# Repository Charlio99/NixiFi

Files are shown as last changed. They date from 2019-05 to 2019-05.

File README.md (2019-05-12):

# NixiFi







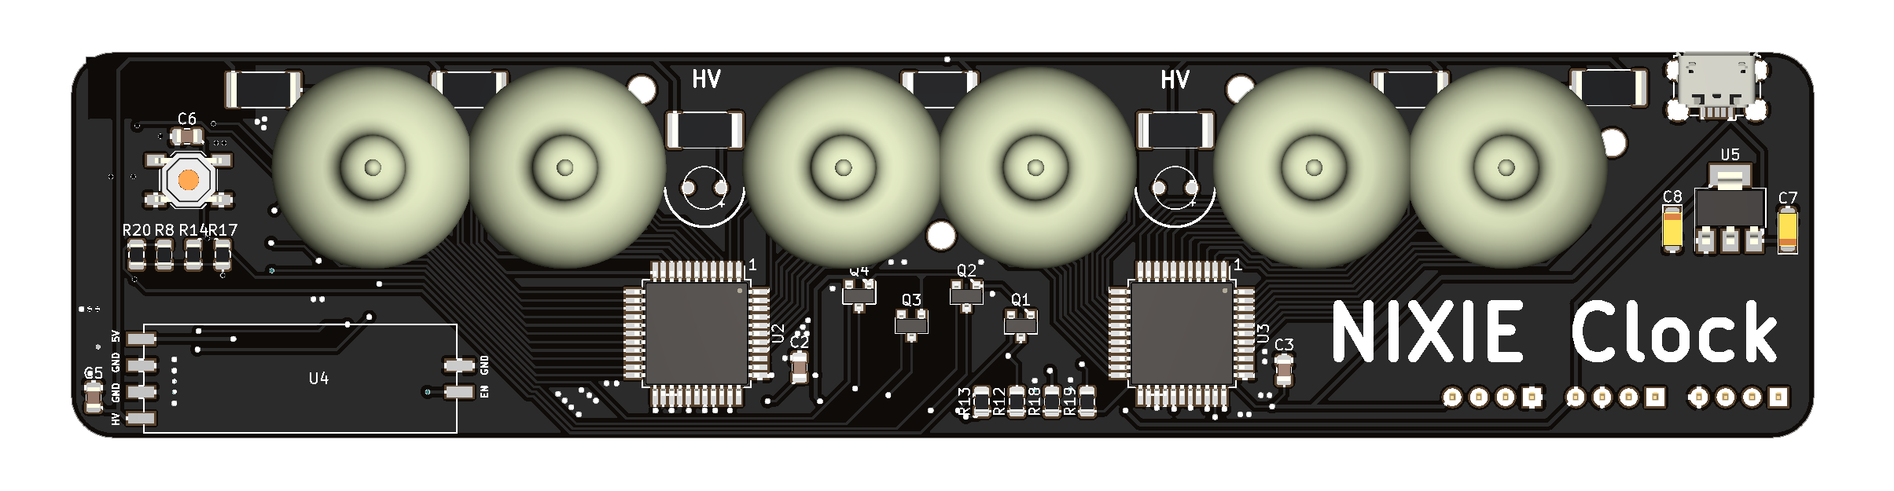
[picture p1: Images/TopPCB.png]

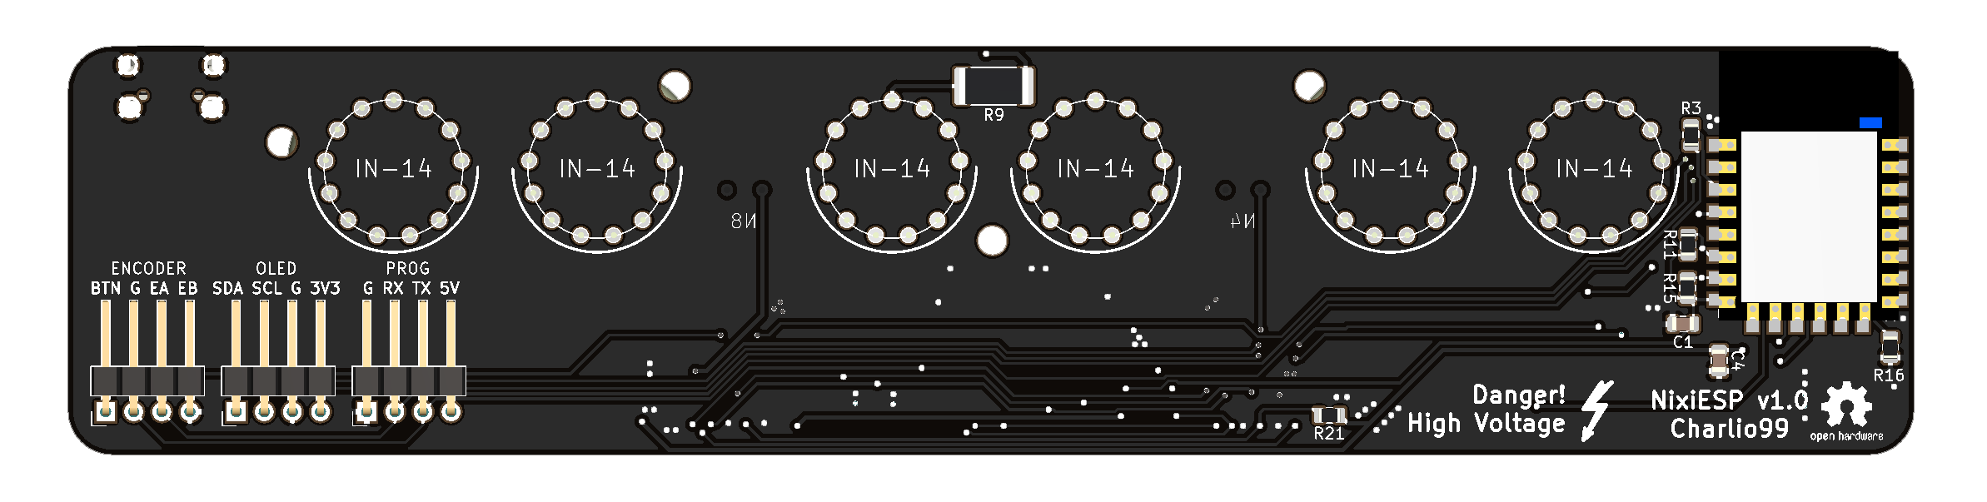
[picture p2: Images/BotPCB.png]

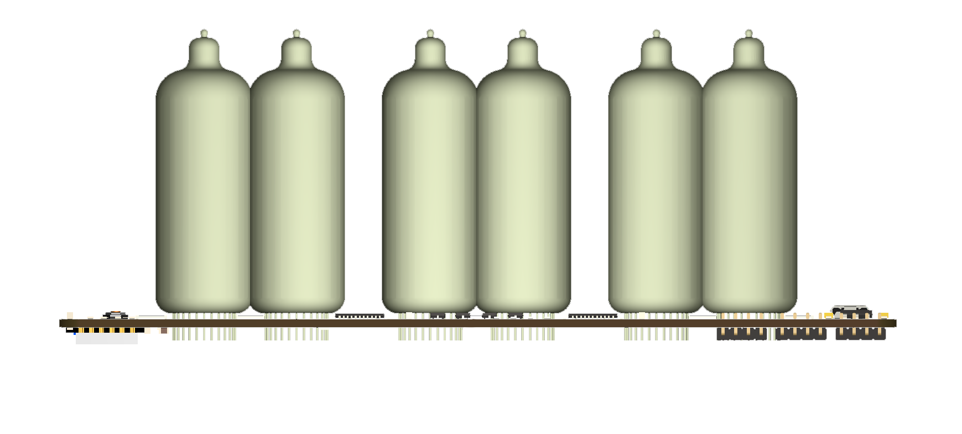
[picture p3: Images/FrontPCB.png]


NixiFi is an all in one WiFi Nixie NTP Clock board, only you have to do is to solder the components and upload the code!.

# Features

  - ESP8266 based (Arduino IDE code).
  - NTP Time.
  - No spare PSUs messing around, the 170v output is handled by a small smd PSU (link in BOM).
  - 5V Powered and it only draws 1.5-2W.
  - Oled display and encoder to configure zone, auto DST, the cathode poisoning prevention, auto shutdown between specific hours, etc.
  - Go over all numbers at specific time to avoid cathode poisoning (can be configured with the OLED display)
  - Plug and play. Once you upload the code, a WiFi network will appear, connect to it following the instructions in the OLED display.

### BOM

I mainly use JLCPCB and LCSC for PCB and components.

| Component | Quantity | Link | Price |
| --- | --- | --- | --- |
| ESP-12E | 1 | https://lcsc.com/product-detail/WIFI-Modules_ESP-12E_C89297.html | $2.2 |
| 170v PSU | 1 | https://www.ebay.es/itm/141728921034 | $9.99 |
| 100nF | 4 | https://lcsc.com/product-detail/Multilayer-Ceramic-Capacitors-MLCC-SMD-SMT_SAMSUNG_CL21B104KBCNNNC_100nF-104-10-50V_C1711.html | $0.46 |
| 1uF | 2 | https://lcsc.com/product-detail/Multilayer-Ceramic-Capacitors-MLCC-SMD-SMT_1uF-106-10-16V_C94122.html | $0.3 |
| 10uF Tantalum | 2 | https://lcsc.com/product-detail/Tantalum-Capacitors_AVX_TAJA106K010RNJ_10uF-106-10-10V_C7177.html | $0.24 |
| USB Micro B | 1 | https://lcsc.com/product-detail/Micro-USB-Connectors_Korean-Hroparts-Elec-U-F-M5DD-Y-1_C91467.html | $0.17 |
| OLED 0.96" | 1 | https://es.aliexpress.com/item/32713614136.html | $1.76 |
| Encoder | 1 | https://es.aliexpress.com/item/Rotary-Encoder-Module-Brick-Sensor-Development-for-arduino-KY-040/32462116984.html | $0.68 |
| 2N7002 | 4 | https://lcsc.com/product-detail/MOSFET_ON-Semicon_2N7002LT1G_ON-Semicon-ON-2N7002LT1G_C16338.html | $0.5 |
| 27K | 6 | https://lcsc.com/product-detail/Chip-Resistor-Surface-Mount_27KR-2702-1_C175357.html | $0.4 |
| 100K | 2 | https://lcsc.com/product-detail/Chip-Resistor-Surface-Mount_100KR-1003-1_C147046.html | $0.85 |
| 10K | 13 | https://lcsc.com/product-detail/Chip-Resistor-Surface-Mount_10KR-103-5_C100047.html | $0.14 |
| Header 4 pins | 3 | https://es.aliexpress.com/item/32847365702.html | $0.77 |
| HV5622 | 2 | https://www.arrow.com/en/products/hv5622pg-g/microchip-technology | $12.32 |
| AMS1117-3.3 | 1 | https://lcsc.com/product-detail/Low-Dropout-Regulators-LDO_AMS_AMS1117-3-3_AMS1117-3-3_C6186.html | $0.57 |
| | | **TOTAL** | **$31.35**|

Take in account that some components must be ordered in larger batches that the quantity needed and shipping costs are not included in the BOM.

### Todos

 - Adapt PCB for making it compatible with IN-8-2 without the need of modifying the IN-8-2. (At the moment it can be done cutting the dot pin and bending pin 1 to be in place of the dot.)
 - Improve README
 
### License

GNU Public License 3.0
Please, if you pretend to use it for comercial uses, contact me before

### Photos
NixiFi rev1.0
NixiFi rev1.0
NixiFi rev1.0

**Open Source FTW, Hell Yeah!**

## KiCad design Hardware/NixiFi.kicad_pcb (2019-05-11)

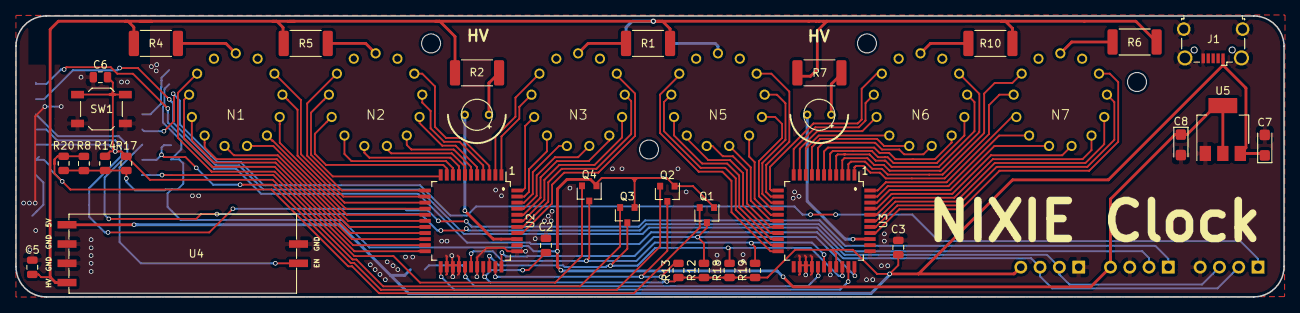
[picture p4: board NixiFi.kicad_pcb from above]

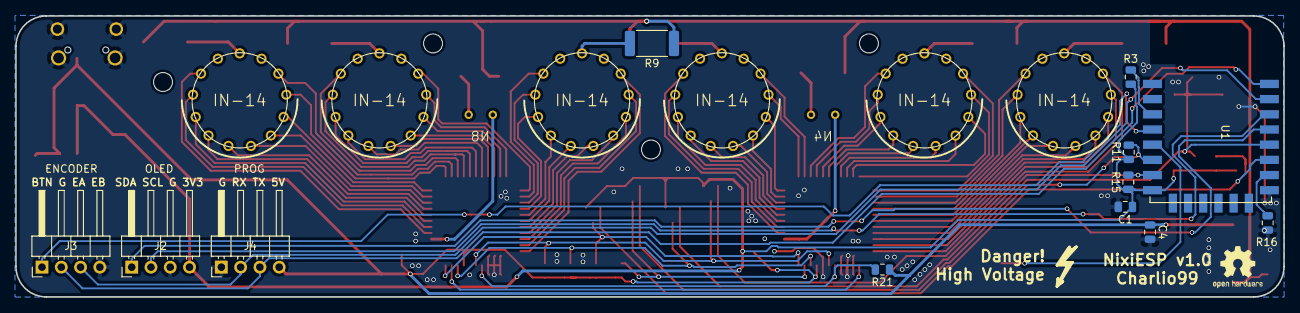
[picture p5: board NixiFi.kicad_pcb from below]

Board: 2 copper layers, 167.0 x 37.0 mm, 51 parts (18 on the bottom side), 92 nets.

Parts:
C1, C6: 100nF; C_0805_2012Metric
C2, C3: 1uF; C_0805_2012Metric
C4, C5: 0.1uF; C_0805_2012Metric
C7, C8: C; CP_EIA-3216-12_Kemet-S
J1: USB_B_Micro; USB_Micro-B_Wuerth_629105150521_CircularHoles
J2: OLED; PinHeader_1x04_P2.54mm_Horizontal
J3: ENCODER; PinHeader_1x04_P2.54mm_Horizontal
J4: PROG; PinHeader_1x04_P2.54mm_Horizontal
N1, N2, N3, N5, N6, N7: IN-14; russian-nixies-IN-14
N4, N8: IN-3; russian-nixies-IN-3
Q1, Q2, Q3, Q4: 2N7002; SOT-23
R1, R4, R5, R6, R9, R10: 27K; R_2512_6332Metric
R2, R7: 100K; R_2512_6332Metric
R3, R8, R11, R12, R13, R14, R15, R16, R17, R18, R19, R20, R21: 10K; R_0805_2012Metric
SW1: PROG_MODE; SW_SPST_TL3342
U1: ESP-12E; ESP-12E_SMD
U2, U3: HV5622; PQFP-44_10x10mm_P0.8mm
U4: PSU; TypeD-PowerSupply
U5: AMS1117-3.3; SOT-223-3_TabPin2

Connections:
+3V3: C1.1, C8.1, J2.4, Q1.1, Q2.1, Q3.1, Q4.1, R3.2, R8.1, R11.1, R14.1, R15.1, R17.1, R20.1, U1.8, U5.2
+5V: C2.1, C3.1, C4.1, C7.1, J1.1, J4.4, R12.1, R13.1, R18.1, R19.1, R21.1, U2.30, U3.30, U4.1, U5.3
/BL: Q1.3, R12.2, U2.33, U3.33
/BL_PIN: Q1.2, R8.2, R20.2, U1.11
/BTN: J3.1, U1.4
/CLK: Q4.3, R19.2, U2.28, U3.28
/CLK_PIN: Q4.2, R15.2, U1.7
/DATA_IN: Q2.3, R13.2, U2.32
/DATA_IN_PIN: Q2.2, R11.2, U1.6
/ENABLE: U1.5, U4.6
/GPIO15: R16.1, U1.10
/LE: Q3.3, R18.2, U2.31, U3.31
/LE_PIN: C6.2, Q3.2, R14.2, R17.2, SW1.1, U1.12
/RXD: J3.3, J4.2, U1.15
/SCL: J2.2, U1.14
/SDA: J2.1, U1.13
/TXD: J3.2, J4.3, U1.16
GND: C1.2, C2.2, C3.2, C4.2, C5.1, C6.1, C7.2, C8.2, J1.5, J1.6, J2.3, J3.4, J4.1, R16.2, SW1.2, U1.9, U2.24, U2.25, U2.26, U2.29, U2.34, U3.24, U3.25, U3.26, U3.29, U3.34, U4.2, U4.3, U4.5, U5.1
HT: C5.2, R1.1, R2.1, R4.1, R5.1, R6.1, R7.1, R9.1, R10.1, U4.4
unnamed: N1.0, U2.13
unnamed: N1.1, U2.22
unnamed: N1.2, U2.21
unnamed: N1.3, U2.20
unnamed: N1.4, U2.19
unnamed: N1.5, U2.18
unnamed: N1.6, U2.17
unnamed: N1.7, U2.16
unnamed: N1.8, U2.15
unnamed: N1.9, U2.14
unnamed: N1.A, R4.2
unnamed: N2.0, U2.3
unnamed: N2.1, U2.12
unnamed: N2.2, U2.11
unnamed: N2.3, U2.10
unnamed: N2.4, U2.9
unnamed: N2.5, U2.8
unnamed: N2.6, U2.7
unnamed: N2.7, U2.6
unnamed: N2.8, U2.5
unnamed: N2.9, U2.4
unnamed: N2.A, R5.2
unnamed: N3.0, U2.37
unnamed: N3.1, U2.2
unnamed: N3.2, U2.1
unnamed: N3.3, U2.44
unnamed: N3.4, U2.43
unnamed: N3.5, U2.42
unnamed: N3.6, U2.41
unnamed: N3.7, U2.40
unnamed: N3.8, U2.39
unnamed: N3.9, U2.38
unnamed: N3.A, R1.2
unnamed: N4.A, R2.2
unnamed: N4.K, U2.36
unnamed: N5.0, U3.13
unnamed: N5.1, U3.22
unnamed: N5.2, U3.21
unnamed: N5.3, U3.20
unnamed: N5.4, U3.19
unnamed: N5.5, U3.18
unnamed: N5.6, U3.17
unnamed: N5.7, U3.16
unnamed: N5.8, U3.15
unnamed: N5.9, U3.14
unnamed: N5.A, R9.2
unnamed: N6.0, U3.3
unnamed: N6.1, U3.12
unnamed: N6.2, U3.11
unnamed: N6.3, U3.10
unnamed: N6.4, U3.9
unnamed: N6.5, U3.8
unnamed: N6.6, U3.7
unnamed: N6.7, U3.6
unnamed: N6.8, U3.5
unnamed: N6.9, U3.4
unnamed: N6.A, R10.2
unnamed: N7.0, U3.37
unnamed: N7.1, U3.2
unnamed: N7.2, U3.1
unnamed: N7.3, U3.44
unnamed: N7.4, U3.43
unnamed: N7.5, U3.42
unnamed: N7.6, U3.41
unnamed: N7.7, U3.40
unnamed: N7.8, U3.39
unnamed: N7.9, U3.38
unnamed: N7.A, R6.2
unnamed: N8.A, R7.2
unnamed: N8.K, U3.36
unnamed: R3.1, U1.3
unnamed: R21.2, U2.27, U3.27
unnamed: U2.23, U3.32

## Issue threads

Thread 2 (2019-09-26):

kicad libraries

alexiumihai1, 2019-09-26:
Hello,
Interesting project.
Can you put the libraries for pcb and schematics please.

Thank you.

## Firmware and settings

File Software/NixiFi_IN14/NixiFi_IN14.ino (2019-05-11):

/* 
 *    ESP Nixie Clock 
 *	  Copyright (C) 2019  Larry McGovern
 *	
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
 *    This program is distributed in the hope that it will be useful,
 *    but WITHOUT ANY WARRANTY; without even the implied warranty of
 *    MERCHANTABILITY or FITNESS FOR A PARTICULAR PURPOSE.  See the
 *    GNU General Public License <http://www.gnu.org/licenses/> for more details.
 */
	
#include <ESP8266WiFi.h>
#include <NTPClient.h>
#include <WiFiUdp.h>
#include <TimeLib.h>
#include <Timezone.h>
#include <Wire.h>
#include <WiFiManager.h>
#include <EEPROM.h>
#include <Adafruit_GFX.h>
#include <Adafruit_SSD1306.h>
#include <avdweb_Switch.h>

#include "NixieDisplay.h"
#include "HvSupply.h"
#include "Globals.h"

#define AP_NAME "NixiFi"
#define AP_PASSWORD "DopeClock"

#define CLOCK_COLON //  Comment out if not using colon separator PCB

const int encoderPinA = 3;
const int encoderPinB = 1;
const int encoderButtonPin = 16;

NixieDisplay nixie;
HvSupply hv_supply;

WiFiUDP ntpUDP;
NTPClient timeClient(ntpUDP, "time.nist.gov", 0, 7200000); // Update time every two hours

// Set timezone rules.  Offsets set to zero, since they will be loaded from EEPROM
TimeChangeRule myDST = {"DST", Second, Sun, Mar, 2, 0};    
TimeChangeRule mySTD = {"STD", First, Sun, Nov, 2, 0};     
Timezone myTZ(myDST, mySTD);

#define OLED_RESET  LED_BUILTIN
#define SCREEN_WIDTH 128 // OLED display width, in pixels
#define SCREEN_HEIGHT 64 // OLED display height, in pixels
Adafruit_SSD1306 display(SCREEN_WIDTH, SCREEN_HEIGHT, &Wire, OLED_RESET);

const int debouncePeriod = 50;
const int longPressPeriod = 3000;  // Set longPressPeriod to 3 seconds.  Will manually turn on/off Nixies if button held for longer than 3 sec.
Switch encoderButton = Switch(encoderButtonPin, INPUT_PULLUP, LOW, debouncePeriod, longPressPeriod);

 
int encoderPos, encoderPosPrev;

enum Menu {
  TOP,
  SETTINGS1,
  SETTINGS2,
  SET_UTC_OFFSET,
  ENABLE_DST,
  SET_12_24,
  BLINK_COLON,
  CATHODE_PROTECT,
  AUTO_SHUTOFF,
  AUTO_SHUTOFF_ENABLE,
  AUTO_SHUTOFF_OFFTIME,
  AUTO_SHUTOFF_ONTIME,
  SHOW_ZERO,
  RESET_WIFI,
  SCREENSAVER_MENU,
  SCREENSAVER
} menu;

// EEPROM addresses
const int EEPROM_addr_UTC_offset  = 0; 
const int EEPROM_addr_DST         = 1;  
const int EEPROM_addr_12_24       = 2; 
const int EEPROM_addr_protect     = 3; 
const int EEPROM_addr_shutoff_en  = 4;
const int EEPROM_addr_shutoff_off = 5;
const int EEPROM_addr_shutoff_on  = 6;
const int EEPROM_addr_showzero    = 7;
const int EEPROM_addr_blink_colon = 8;
const int EEPROM_addr_screensaver = 9;

bool enableDST;         // Flag to enable DST
bool set12_24;          // Flag indicating 12 vs 24 hour time (0 = 12, 1 = 24);
bool showZero;          // Flag to indicate whether to show zero in the hour ten's place
bool enableBlink;       // Flag to indicate whether center colon should blink

uint8_t ssOption;       // Screen saver option (0=disabled, 1=scrolling image, 2=turn off OLED)

uint8_t interval_indx; // Cathode protection interval index
const int num_intervals = 8;
const int intervals[num_intervals] = {0, 1, 5, 10, 15, 20, 30, 60};  // Intervals in minutes, with 0 = off

bool enableAutoShutoff; // Flag to enable/disable nighttime shut off
int autoShutoffOfftime, autoShutoffOntime;  // On and off times from 0 to 95 in 15 minute intervals

time_t protectTimer = 0, menuTimer = 0;
bool nixieOn = true, manualOverride = false;
bool initProtectionTimer = false;  // Set true at the top of the hour to synchronize protection timer with clock

// Screensaver Bitmaps
#define INVADER_HEIGHT   16
#define INVADER_WIDTH    24
static const unsigned char PROGMEM invader1_bmp[] =
{ B00000110, B00000000, B01100000,
  B00000110, B00000000, B01100000,
  B01100001, B10000001, B10000110,
  B01100001, B10000001, B10000110,
  B01100111, B11111111, B11100110,
  B01100111, B11111111, B11100110,
  B01111110, B01111110, B01111110,
  B01111110, B01111110, B01111110,
  B01111111, B11111111, B11111110,
  B01111111, B11111111, B11111110,
  B00011111, B11111111, B11111000,
  B00011111, B11111111, B11111000,
  B00000110, B00000000, B01100000,
  B00000110, B00000000, B01100000,
  B00011000, B00000000, B00011000,
  B00011000, B00000000, B00011000};
        
static const unsigned char PROGMEM invader2_bmp[] =
{ B00000110, B00000000, B01100000,
  B00000110, B00000000, B01100000,
  B00000001, B10000001, B10000000,
  B00000001, B10000001, B10000000,
  B00000111, B11111111, B11100000,
  B00000111, B11111111, B11100000,
  B00011110, B01111110, B01111000,
  B00011110, B01111110, B01111000,
  B01111111, B11111111, B11111110,
  B01111111, B11111111, B11111110,
  B01100111, B11111111, B11100110,
  B01100111, B11111111, B11100110,
  B01100110, B00000000, B01100110,
  B01100110, B00000000, B01100110,
  B00000001, B11100111, B10000000,
  B00000001, B11100111, B10000000};
   
void setup() {
  Serial.begin(115200);
  pinMode(encoderPinA, INPUT_PULLUP);
  pinMode(encoderPinB, INPUT_PULLUP);

  display.begin(SSD1306_SWITCHCAPVCC, 0x3C);  // OLED I2C Address, may need to change for different device,
                                              // Check with I2C_Scanner
  display.setTextSize(1);
  display.setTextColor(WHITE);
  display.clearDisplay();
  
  display.setCursor(0,0);
  display.println("Connecting...");
  display.println();
  display.println("Cycle Power after a");
  display.println("few minutes if no");
  display.print("connection.");
  display.display();

    // Setup WiFiManager
  WiFiManager MyWifiManager;
  MyWifiManager.setAPCallback(configModeCallback);
  MyWifiManager.autoConnect(AP_NAME,AP_PASSWORD); // Default password is PASSWORD, change as needed
  
  display.clearDisplay();
  display.setCursor(0,0);
  display.print("Wifi Connected");
  display.display();

  timeClient.begin();

  display.setCursor(0,28);
  display.println("Updating local time");
  display.display();
  while (!timeClient.update()) {
    delay(500);
    display.print(".");
    display.display();
  }

  EEPROM.begin(10);
  
  // Read UTC offset from EEPROM
  int utc_offset = (((int)EEPROM.read(EEPROM_addr_UTC_offset)+12) % 24) - 12;

  // Read Daylight Savings Time setting from EEPROM
  enableDST = EEPROM.read(EEPROM_addr_DST) != 0;

  mySTD.offset = utc_offset * 60;
  myDST.offset = mySTD.offset;
  if (enableDST) {
    myDST.offset += 60;
  }
  myTZ = Timezone(myDST, mySTD);

  // Read 12/24 hour setting from EEPROM
  set12_24 =  EEPROM.read(EEPROM_addr_12_24) != 0;

  // Read cathode proection interval from EEPROM
  interval_indx = EEPROM.read(EEPROM_addr_protect);
  if (interval_indx >= num_intervals) interval_indx = 0;

  // Read auto shutoff settings
  enableAutoShutoff  = EEPROM.read(EEPROM_addr_shutoff_en) != 0;
  autoShutoffOfftime = (int)EEPROM.read(EEPROM_addr_shutoff_off);
  autoShutoffOntime  = (int)EEPROM.read(EEPROM_addr_shutoff_on);
  if (autoShutoffOfftime > 95) autoShutoffOfftime = 0;  // 96 15-minute intervals in day
  if (autoShutoffOntime > 95) autoShutoffOntime = 0;

  // Read show zero setting from EEPROM
  showZero = EEPROM.read(EEPROM_addr_showzero) != 0;

  // Read colon blink setting from EEPROM
  enableBlink = EEPROM.read(EEPROM_addr_blink_colon) != 0;

  // Read screensaver setting from EEPROM
  ssOption = EEPROM.read(EEPROM_addr_screensaver);
  if (ssOption > 2) ssOption = 0;
  
  menu = TOP;
  updateSelection();

  timeClient.update();
  setTime(myTZ.toLocal(timeClient.getEpochTime()));
  hv_supply.begin();
  nixie.begin();
  displayTime();
  menuTimer = now();
}

void loop() {  
  updateEncoderPos();
  encoderButton.poll();

  // If button held for longer than 3 seconds, toggle Nixie tubes on/off
  if (encoderButton.longPress()){
    manualOverride = true;  // Overrides auto shutoff for this period
    nixieOn = !nixieOn;
    menu = TOP;
    updateSelection(); 
  }

  if (encoderButton.pushed()) {
    menuTimer = now();  
    updateMenu();
   }

  timeClient.update();
  setTime(myTZ.toLocal(timeClient.getEpochTime()));

  // Cathode protection logic
  if (interval_indx > 0) {  // Cathode protection is enabled
    if ((menu != SET_UTC_OFFSET) && (menu != ENABLE_DST)) { // Changing UTC offset or DST setting can disrupt protection timer
      // At the first top of the hour, initialize cathode protection logic timer
      if (!initProtectionTimer && (minute() == 0)) {  
        protectTimer = 0;   // Ensures protection logic will be immediately triggered                                     
        initProtectionTimer = true;
      }
      if ((now() - protectTimer) >= 60 * intervals[interval_indx]) {
        protectTimer = now();
        // The current time can drift slightly relative to the protectTimer when NIST time is updated
        // Need to make a small adjustment to the timer to ensure it is triggered at the minute change
        protectTimer -= ((second()+30)%60 - 30);  
        if (nixieOn) cathodeProtect();
      }      
    }
  }
  
  static time_t prevTime = 0, refreshScreensaver = 0;
  if (now() != prevTime) { // Update time every second
    prevTime = now();
    evalShutoffTime();     // Check whether nixies should be turned off (Auto shutoff mode)
    displayTime();         // Update the time displayed on nixies and on OLED
    if (menu == SCREENSAVER) {
      if (now() - refreshScreensaver > 1800) { // OLED bitmap occasionally can get corrupted after a few hours
        updateSelection();                     // This will refresh screen saver bitmap every 30 minutes 
        refreshScreensaver = now();                 
      }
      else if ((ssOption == 1) && (mod(now(),3)==0)) { // Switch screensaver scroll direction every 3 seconds
        long r = random(2);  // Randomize switch between left and right
        if (r == 0) display.startscrolldiagright(0x00, 0x07);
        else display.startscrolldiagleft(0x00, 0x07);
      }
    }
  }
  // Reset screen to screensaver (if enabled) or top level if encoder inactive for more than 60 seconds
  // Note that UTC offset and DST setting changes can change now() by one hour
  // (3600 seconds), so modulus operator is needed
  if ((mod(now() - menuTimer, 3600) > 60) && (menu != SCREENSAVER)) { 
    if (ssOption > 0) {
      menu = SCREENSAVER;
      updateSelection();
      refreshScreensaver = now();      
    }
    else if (menu != TOP) {
      menu = TOP;
      updateSelection();     
    } 
  }
}

void cathodeProtect() {
  nixie.runSlotMachine();
  /*
  int hour12_24 = set12_24 ? (unsigned char)hour() : (unsigned char)hourFormat12();
  unsigned char hourBcd = decToBcd((unsigned char)hour12_24);
  unsigned char minBcd  = decToBcd((unsigned char)minute());
  unsigned char dh1 = (hourBcd >> 4), dh2 = (hourBcd & 15); 
  unsigned char dm1 = (minBcd >> 4),  dm2 = (minBcd & 15);

  // All four digits will increment up at 10 Hz.
  // At T=2 sec, individual digits will stop at 
  // the correct time every second starting from 
  // the right and ending on the left
  for (int i = 0; i <= 50; i++){
    if (i >= 20) dm2 = (minBcd & 15); 
    if (i >= 30) dm1 = (minBcd >> 4); 
    if (i >= 40) dh2 = (hourBcd & 15);
    if (i == 50) dh1 = (hourBcd >> 4);
    digitalWrite(latchPin, LOW);
    shiftOut(dataPin, clockPin, MSBFIRST, (dh1 << 4) | dh2);
    shiftOut(dataPin, clockPin, MSBFIRST, (dm1 << 4) | dm2);
    digitalWrite(latchPin, HIGH);
    incMod10(dh1); incMod10(dh2);
    incMod10(dm1); incMod10(dm2);
    delay(100);
  }
  */
}

inline void incMod10(unsigned char &x) { x = (x + 1 == 10 ? 0: x + 1); };

void displayTime(){
   char tod[10], time_str[20], date_str[20];
   const char* am_pm[] = {"AM", "PM"};
   const char* month_names[] = {"Jan", "Feb", "March", "April", "May", "June", "July", "Aug", "Sept", "Oct", "Nov", "Dec"};
   int hour12_24 = set12_24 ? (unsigned char)hour() : (unsigned char)hourFormat12();
   unsigned char hourBcd = decToBcd((unsigned char)hour12_24);
   unsigned char minBcd  = decToBcd((unsigned char)minute());
   bool colonBlinkState = (bool)(second() % 2);

   hv_supply.switchOn();

   if (!nixieOn) {
    hourBcd = 255; 
    minBcd = 255;
    hv_supply.switchOff();
    colonBlinkState = false;
   }
   else if (!enableBlink) {
    colonBlinkState = true;
   }

    // Enable and disable the right segments
    nixie.disableSegments(hourTens, 10);
    nixie.disableSegments(hourUnits, 10);
    nixie.disableSegments(minuteTens, 10);
    nixie.disableSegments(minuteUnits, 10);
    nixie.disableSegments(secondTens, 10);
    nixie.disableSegments(secondUnits, 10);
    nixie.enableSegment(hourTens[(hour12_24 / 10) % 10]);
    nixie.enableSegment(hourUnits[hour12_24 % 10]);
    nixie.enableSegment(minuteTens[(minute() / 10) % 10]);
    nixie.enableSegment(minuteUnits[minute() % 10]);
    nixie.enableSegment(secondTens[(second() / 10) % 10]);
    nixie.enableSegment(secondUnits[second() % 10]);

    if (!showZero && ((hourBcd >> 4) == 0)) { // If 10's digit is zero, we don't want to display a zero
    nixie.disableSegments(hourTens, 10);
   }
  
    // Flash the dots once per second
    if (!colonBlinkState) {
      nixie.disableSegment(leftDot);
      nixie.disableSegment(rightDot);
    } else {
      nixie.enableSegment(leftDot);
      nixie.enableSegment(rightDot);
    }
  
    // Write to display
    nixie.updateDisplay();

   //digitalWrite(colonPin, colonBlinkState); // Blink colon pin
   
   if ((menu == TOP) || (menu == SET_UTC_OFFSET)) {
      formattedTime(tod, hour12_24, minute(), second());
      sprintf(time_str, "%s %s", tod, am_pm[isPM()]);
      sprintf(date_str, "%s %d, %d", month_names[month() - 1], day(), year());
      display.fillRect(20,28,120,8,BLACK);
      display.setCursor(20,28);
      display.print(time_str);
      if (enableDST) {
        if (myTZ.utcIsDST(timeClient.getEpochTime())) {
          display.print(" DST");
        }
        else {
          display.print(" STD");
        }
      }
      display.setCursor(20,36);
      display.print(date_str);
      display.display();
   }
}

unsigned char decToBcd(unsigned char val)
{
  return ( ((val/10)*16) + (val%10) );
}

#define colonDigit(digit) digit < 10 ? ":0" : ":"
void formattedTime(char *tod, int hours, int minutes, int seconds)
{
  sprintf(tod, "%d%s%d%s%d", hours, colonDigit(minutes), minutes, colonDigit(seconds), seconds);  // Hours, minutes, seconds
}

void evalShutoffTime() {  // Determine whether Nixie tubes should be turned off
  
  if (!enableAutoShutoff) return;
  
  int mn = 60*hour() + minute();
  int mn_on = 15*autoShutoffOntime;  
  int mn_off = 15*autoShutoffOfftime;

  static bool prevShutoffState = true;  
  if ( ((mn_off < mn_on) &&  (mn > mn_off) && (mn < mn_on)) ||  // Nixies should be off
        (mn_off > mn_on) && ((mn > mn_off) || (mn < mn_on))) { 
     if (!manualOverride) nixieOn = false;
     if (prevShutoffState == true) manualOverride = false; 
     prevShutoffState = false;
  }
  else {  // Nixies should be on
    if (!manualOverride) nixieOn = true;
    if (prevShutoffState == false) manualOverride = false; 
    prevShutoffState = true;
  }
    
}

void updateEncoderPos() {
    static int encoderA, encoderB, encoderA_prev;   

    encoderA = digitalRead(encoderPinA); 
    encoderB = digitalRead(encoderPinB);
 
    if((!encoderA) && (encoderA_prev)){ // A has gone from high to low 
      encoderPosPrev = encoderPos;
      encoderB ? encoderPos++ : encoderPos--;  
      menuTimer = now();
      if (menu != TOP) {
        updateSelection();
      }    
    }
    encoderA_prev = encoderA;     
}

#ifdef CLOCK_COLON
  const int n_set1 = 6;  // 6 menu items on Settings 1
#else
  const int n_set1 = 5;  // Otherwise, only 5 items
#endif

void updateMenu() {  // Called whenever button is pushed

  switch (menu) {
    case TOP:
      menu = SETTINGS1;
      break;
      
    case SCREENSAVER:
      display.stopscroll();
      menu = SETTINGS1;
      break;
      
    case SETTINGS1:
      switch (mod(encoderPos,n_set1)) {
        case 0: // Timezone Offset
          menu = SET_UTC_OFFSET;
          break;
        case 1: // Enable DST
          menu = ENABLE_DST;
          break;
        case 2: // 12/24 Hours
          menu = SET_12_24;
          break;
          
#ifdef CLOCK_COLON
        case 3: // Blink Colon
          menu = BLINK_COLON;
          break;  
        case 4: // More Options
          menu = SETTINGS2;
          break;
        case 5: // Return
          menu = TOP;
          break;
#else
        case 3: // More Options
          menu = SETTINGS2;
          break;
        case 4: // Return
          menu = TOP;
          break;
#endif
      }
      break;
    case SETTINGS2:
      switch (mod(encoderPos,6)) {
        case 0: // Cathod Protection
          menu = CATHODE_PROTECT;
          break;
        case 1: // Auto Shut off
          menu = AUTO_SHUTOFF;
          break;
        case 2: // Enable Screensaver
          menu = SCREENSAVER_MENU;
          break;
        case 3: // Show Zero
          menu = SHOW_ZERO;
          break;
        case 4: // Reset Wifi
          menu = RESET_WIFI;
          break;
        case 5: // Return
          menu = SETTINGS1;
          break;
      }
      break;
      
    case RESET_WIFI:
      if (mod(encoderPos, 2) == 1){  // Selection = YES
        resetWiFi();
        menu = TOP; 
      }
      else {  // Selection = NO
        menu = SETTINGS1;
      }
      break;
      
    case SET_UTC_OFFSET:
      EEPROM.write(EEPROM_addr_UTC_offset, (unsigned char)(mod(mySTD.offset/60,24))); 
      EEPROM.commit();
      initProtectionTimer = false;
      menu = SETTINGS1;
      break;
      
    case ENABLE_DST:
      EEPROM.write(EEPROM_addr_DST, (unsigned char)enableDST);
      EEPROM.commit();
      initProtectionTimer = false;
      menu = SETTINGS1; 
      break;
      
    case SET_12_24:
      EEPROM.write(EEPROM_addr_12_24, (unsigned char)set12_24);
      EEPROM.commit();
      menu = SETTINGS1;
      break; 

    case BLINK_COLON:
      EEPROM.write(EEPROM_addr_blink_colon, (unsigned char)enableBlink);
      EEPROM.commit();
      menu = SETTINGS1;
      break;
     
    case CATHODE_PROTECT: 
      EEPROM.write(EEPROM_addr_protect, interval_indx);
      EEPROM.commit();
      initProtectionTimer = false;
      protectTimer = 0;
      menu = SETTINGS2;
      break;
      
    case AUTO_SHUTOFF: 
      switch (mod(encoderPos,4)) {
        case 0: 
          menu = AUTO_SHUTOFF_ENABLE;
          break;
        case 1: 
          menu = AUTO_SHUTOFF_OFFTIME;
          break;
        case 2: 
          menu = AUTO_SHUTOFF_ONTIME;
          break;
        case 3: 
          menu = SETTINGS2;
          break;
      }
      break;
      
    case AUTO_SHUTOFF_ENABLE:
      EEPROM.write(EEPROM_addr_shutoff_en, (unsigned char)enableAutoShutoff);
      EEPROM.commit();
      menu = AUTO_SHUTOFF;
      break;
      
    case AUTO_SHUTOFF_OFFTIME:  
      EEPROM.write(EEPROM_addr_shutoff_off, (unsigned char)autoShutoffOfftime);
      EEPROM.commit();
      menu = AUTO_SHUTOFF;
      break;
      
    case AUTO_SHUTOFF_ONTIME: 
      EEPROM.write(EEPROM_addr_shutoff_on, (unsigned char)autoShutoffOntime);
      EEPROM.commit();
      menu = AUTO_SHUTOFF;
      break;
      
    case SCREENSAVER_MENU: 
      {
        int opt = mod(encoderPos,4);
        if (opt < 3) {
          ssOption = (uint8_t) opt;
          EEPROM.write(EEPROM_addr_screensaver, (unsigned char)ssOption);
          EEPROM.commit();
        }
        else menu = SETTINGS2;  // Return
      }
      break;
      
    case SHOW_ZERO: 
      EEPROM.write(EEPROM_addr_showzero, (unsigned char)showZero);
      EEPROM.commit();
      menu = SETTINGS2;
      break;
  }
  encoderPos = 0;  // Reset encoder position
  encoderPosPrev = 0;
  updateSelection(); // Refresh screen
}
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

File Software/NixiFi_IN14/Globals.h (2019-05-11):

#ifndef Globals_h
#define Globals_h

// Pins to HV5622 shift registers
#define PIN_HV_LE 0
#define PIN_HV_BL 2
#define PIN_HV_DATA 12
#define PIN_HV_CLK 13

// Pin to DC/DC 170V enable pin
#define PIN_HV_EN 14

#endif

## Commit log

2019-04-19 Working version rev1.0
    [NixiFi.kicad_pcb, NixiFi.sch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]
2019-05-11 Fully working version and tested
    [NixiFi.kicad_pcb]

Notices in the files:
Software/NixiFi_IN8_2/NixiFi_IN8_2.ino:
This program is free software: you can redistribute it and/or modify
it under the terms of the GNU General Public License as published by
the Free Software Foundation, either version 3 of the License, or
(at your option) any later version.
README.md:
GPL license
